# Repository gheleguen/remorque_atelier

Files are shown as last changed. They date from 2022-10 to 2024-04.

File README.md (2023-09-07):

# Une Remorque atelier

### Un support à l'animation d'ateliers de coopérations

---

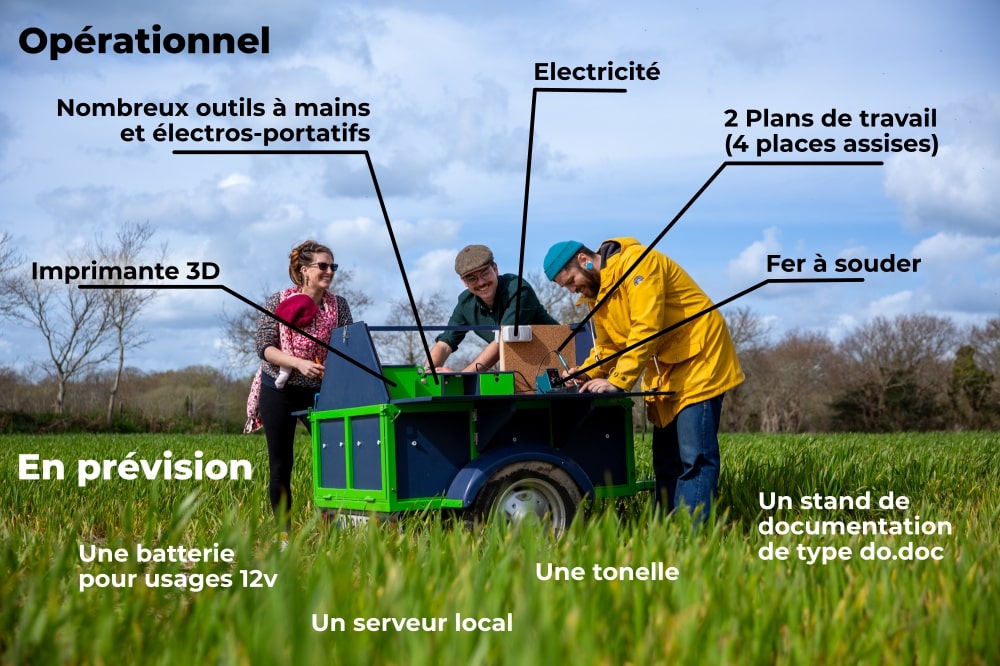
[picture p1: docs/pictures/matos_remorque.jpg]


Faciliter des ateliers coopératifs en tous lieux, étendre les buts des Fab Lab et autres ateliers coopératifs, pouvoir se déployer hors les mures, pour toucher d'autres publics, animer des lieux de passages. Tel est l'objectif de cette petite remorque.

Ma conception est voulu comme open source, je documente mes travaux, mes idées, mes conceptions. Que vous souhaitiez reproduire cet outil à l'identique ou simplement vous en inspirer, vous trouverez ici je l'éspère un maximum d'informations pour vous lancer. 
 
En cas de besoin n'hésitez pas à me contacter. Vous trouverez mes coordonnées ici : https://www.guillaumeleguen.xyz/contact.html. 

## 1/ Toutes les clés pour se lancer

### 1.1 Télécharger l'archive

Avant toute chose, [télécharger l'archive du projet](https://github.com/gheleguen/remorque_atelier/archive/refs/heads/main.zip). C'est dans ce dossier que se trouve tous les fichiers de doicumantations mais aussi les fichiers de découpes ou les modèles d'impression 3D. 

**Ou passer par Git Hub**

Se rendre dans le [git hub](https://github.com/gheleguen/remorque_atelier) et télécharger l'archive complète du projet. 

**Ou en lignes de commandes**

 - Ouvrir un terminal linux,
 - Si ce n'est pas déjà fait installer ```git``` : <pre>sudo apt install git</pre>
 - Se placer dans le dossier de votre ordinateur où vous souhaitez installer enregistrer l'archive.
 - Cloner l'archive : <pre>git clone https://github.com/gheleguen/remorque_atelier</pre> 

### 1.2 L'arborescence de l'archive

 - **docs :** Est le dossier qui contient les documents et images qui constituent la documentation.  Ce sont des fichiers marckdown (.md) que l'on peut ouvrir avec un éditeur de texte.

 - **Hardware :** Le dossier qui contient les fichiers d'impressions 3D, de découpe laser...

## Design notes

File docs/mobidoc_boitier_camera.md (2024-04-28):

# Caméra pour Mobidoc
## 1/ Introduction
La caméra est l'élément central de la station de documentation mobidoc. La documentation de [l'atelier des chercheurs](https://latelier-des-chercheurs.fr/) propose d'utiliser une webcam USB. J'ai fais le choix d'utiliser plutôt une camér raspberry pour sa facilité d'usage avec une raspberry pi.

J'ai donc choisis la configuration suivante :
 * D'utiliser la pi cam HQ (Haute Qualité).
 * Avec un convertisseur CSI HDMI pour avoir un câble HDMi qui est plus facile à manipuler que la nappe. 
 * Un objectif à focale variable. 
 
<section style="border: 2px solid; padding: 20px; border-radius:20px;" >
Cette version est un dérivé du travail produit par l'atelier des chercheurs :
	<p xmlns:cc="http://creativecommons.org/ns#" xmlns:dct="http://purl.org/dc/terms/"><a property="dct:title" rel="cc:attributionURL" href="https://latelier-des-chercheurs.fr/docs/station-de-documentation">Mobidoc</a> by <a rel="cc:attributionURL dct:creator" property="cc:attributionName" href="https://latelier-des-chercheurs.fr/">L'atelier des chercheurs</a> is licensed under <a href="https://creativecommons.org/licenses/by-nc-sa/4.0/?ref=chooser-v1" target="_blank" rel="license noopener noreferrer" style="display:inline-block;">CC BY-NC-SA 4.0</a></p>
</section>

## 2/ Matériel et fournitures
### 2.1 Fournitures

|Dénomination|Visuel|Mes fournitures|Qt|
|---|---|-----|--|
|Pi camera HQ|Picam HQ|[GoTronic](https://www.gotronic.fr/art-camera-hq-12-mpx-c-cs-sc0261-33781.htm)|1|
|Convertisseur CSI HDMI pour pi cam|Convertisseur CSI HDMI|[Gotronic](https://www.gotronic.fr/art-extension-camera-csi-via-hdmi-b0091-34398.htm)|1 lot de 2|
|Câble HDMI|||1|
|Filament PETG ou PLA pour imprimante 3D|||4m|
|Vis M2*8mm|||4|
|Visserie M2,5||||
|Vis M6*30mm tête hexagonale|||1|
|Ecrou M6|||1|
|Entretoises en laiton M2,5*5+5mm|||3|
|Entretoises en laiton M2,5*11+6mm|||3|
|Rondelles M2,5|||3|

### 2.2 Matériel
 * Imprimante 3D ;
 * Clés alens ;
 * Tournevis ;

### 2.3 Impressions
 * Boitier pour caméra Pi HQ ;
 * Couvercle pour caméra Pi HQ :
 * Rotule ;
 * Rotule femelle ;
 * 2 vis ;

## 3/ Assemblage
 * Positionner l'écrou M6 dans son emplacement au fond du boîtier ;
![Positionner l'écrou M6]()
 * Insérer la vis M6*30mm dans la rotule ;
 * Visser la rotule à l'arrière du boitier ; 
![Visser la rotule]()
 * Rassembler, 4 vis M2*8mm et un convertisseur CSI HDMI ;
![Rassembler, 4 vis M2*8mm et un convertisseur CSI HDMI]()
 * Positionner le convertisseur CSI HDMI ;
 * Veiller à placer le connecteur HDMI face à l'ouverture ;
 * Visser le convertisseur au fond du boîtier à l'aide d'une clé allen ;
![Positionnement du convertisseur CSI HDMI]()
 * Rassembler 3 entretoises en laiton M2,5*5+5mm ;
![Rassembler 3 entretoises en laiton]()
 * Visser les 3 entretoises aux emplacements prévus ; 
![Visser les 3 entretoises]()
 * Connecter la nappe à la picam. Attention ! La partie bleu doit se retrouver sur le dos de la caméra.
![Connecter la nappe]()
 * Rassembler 3 entretoises M2,5*11+6mm et 3 rondelles M2,5;
![Rassembler 3 entretoises M2,5*11+6mm et 3 rondelles M2,5]()
 * Positionner la piCam sur son emplacement ;
 * La maintenir en vissant les 3 entretoises avec une rondelle pour supprimer le jeu ;
 * Visser l'objectif en enlevant la bague C-CS ; 
![Positionner la caméra]()

 * Refermer le couvercle ;
 * Il sera nécessaire pour cela de retirer temporairement les 2 vis de réglages de l'objectif. 
 * Visser le couvercle.

## Licence
<p xmlns:cc="http://creativecommons.org/ns#" xmlns:dct="http://purl.org/dc/terms/"><a property="dct:title" rel="cc:attributionURL" href="https://remorque-atelier.readthedocs.io/fr/latest/">Mobidoc</a> by <a rel="cc:attributionURL dct:creator" property="cc:attributionName" href="https://www.guillaumeleguen.xyz/">Guillaume Leguen</a> is licensed under <a href="https://creativecommons.org/licenses/by-nc-sa/4.0/?ref=chooser-v1" target="_blank" rel="license noopener noreferrer" style="display:inline-block;">CC BY-NC-SA 4.0</a></p>

Cette version est un dérivé du travail produit par l'atelier des chercheurs :
<p xmlns:cc="http://creativecommons.org/ns#" xmlns:dct="http://purl.org/dc/terms/"><a property="dct:title" rel="cc:attributionURL" href="https://latelier-des-chercheurs.fr/docs/station-de-documentation">Mobidoc</a> by <a rel="cc:attributionURL dct:creator" property="cc:attributionName" href="https://latelier-des-chercheurs.fr/">L'atelier des chercheurs</a> is licensed under <a href="https://creativecommons.org/licenses/by-nc-sa/4.0/?ref=chooser-v1" target="_blank" rel="license noopener noreferrer" style="display:inline-block;">CC BY-NC-SA 4.0</a></p>

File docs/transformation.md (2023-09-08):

# Transformation

## 1/ Mes besoins

 Mon projet de remorque est destiné à servir de support pour animer des ateliers particulièrement pour de l'électronique, des ateliers de réparations, ou de menuiserie simple. J'ai donc besoin d'électricité à poste, avec potentiellement un mini serveur local pour partager des données. 
 
Mon souhait était également de combiner un espace qui se déploie en un geste tout en restant compacte pour la route. Mon cahier des charges était donc : 

 - Un plan de travail repliable et déployable en quelques gestes ; 
 - Pouvoir accueillir jusqu'à 4 places assises ; 
 - Un moyen de distribuer l'électricité dans la remorque et pouvoir se brancher facilement ;
 - Laisser un accés facile à quelques outils et ustensiles de bases ;
 - Intégrer une solution d'alimentation (câble et peut-être un jour une batterie.)
 - Ne pas dépasser le poids maximum (PTAC 500kg).

## 2/ Mes solutions
 - Une super-structure en bois placé sur le dessus de la remorque comportant 2 plateaux pouvants se déployer.
 - Ces plateaux reposent sur des supports rétractables. 
 - On peut entre les deux côtés de la remorque poser des cloisons avec des étagères, tirroirs, trappes. 
 - Un touret de câble sera placé dans la remorque pour pouvoir alimenter les besoins de la remorque via un branchement sur secteur (Ou prise caravane). 
 
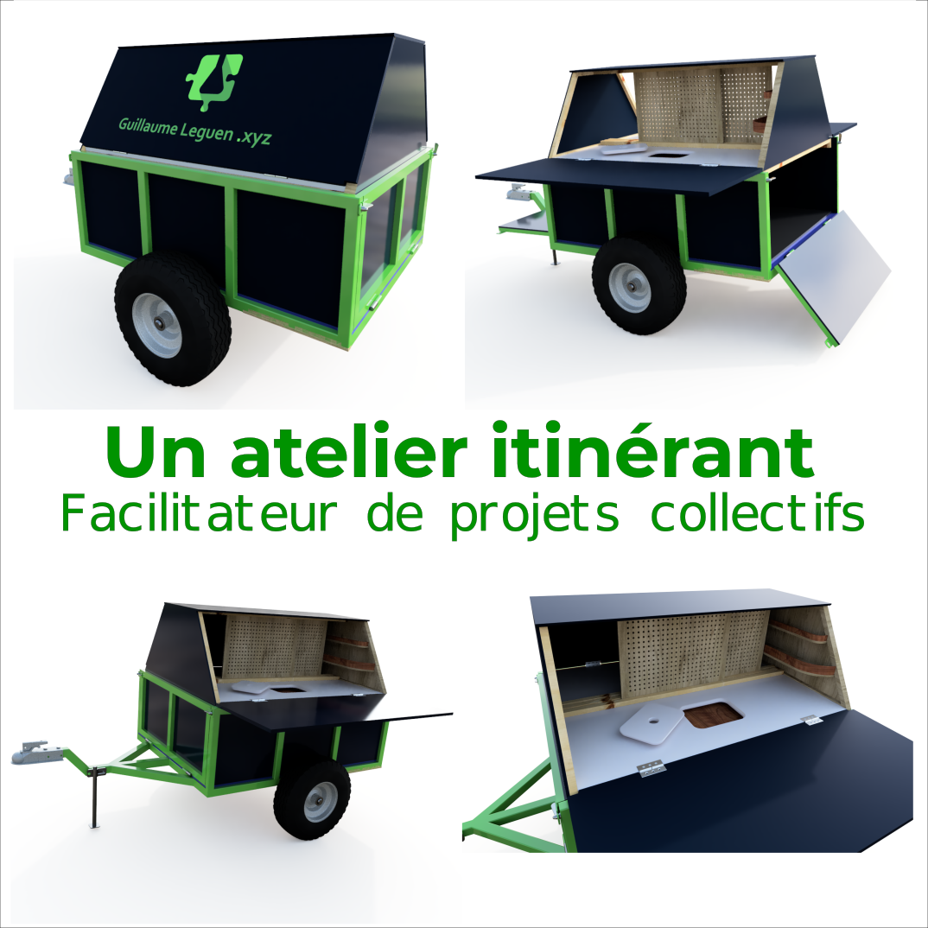
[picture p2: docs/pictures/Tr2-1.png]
projet_remorque

Notes: L'aménagement intérieur sur ce visuel n'est pas tout à fait celui que j'ai réalisé (cf. Chapitre, Amménagement).

## 3/ Réalisation 

### 1.1. La structure en bois

 - Sur les bords internes de la remorque boulonner (de préférence avec la structure) deux tasseaux à fleur du haut de la remorque. 
 - Fixer deux traverses par assemblage mi bois.
 - Attention il est nécéssaire de réaliser cela en s'assurant qu'il est bien possible de fermer les portes de la remorque. 
 - Le fait de boulonner et non visser ce cadre va permettre de pouvoir par la suite désolidariser la super-structure de la remorque et permettre ainsi de pouvoir utiliser la remorque seule occasionellement. 
 - On peut ajouter deux traverses en bois, pour soutenir le futur plateau. 

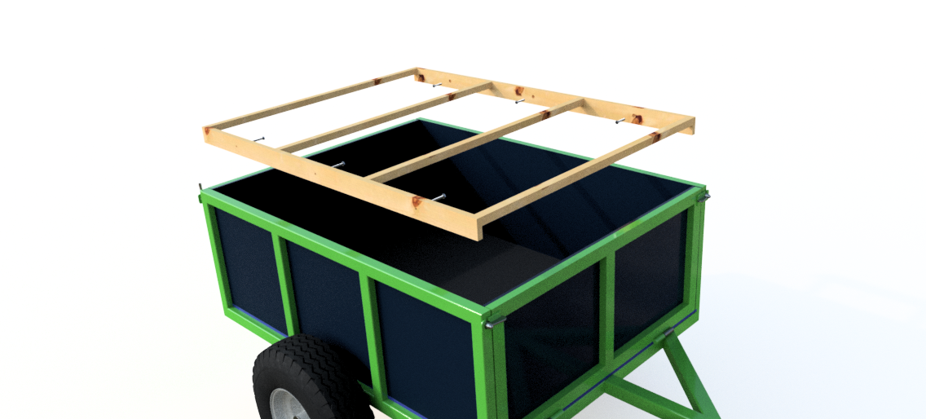
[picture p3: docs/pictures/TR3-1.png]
TR3-1

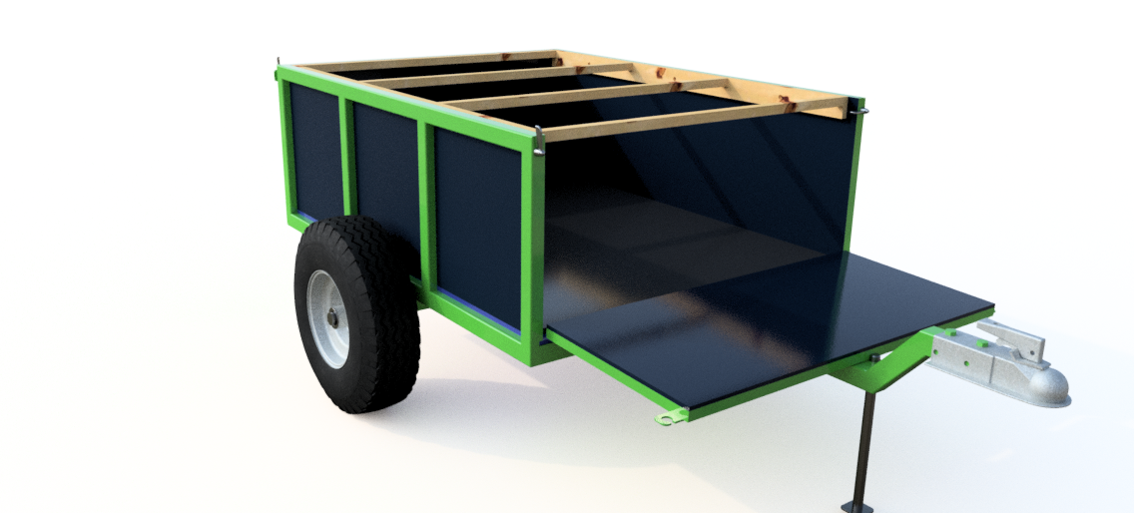
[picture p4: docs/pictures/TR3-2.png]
TR3-2


 - Fabriquer en bois 2 trapèzes à l'aide de tasseaux (dans mon cas 21*21mm en pin).
 - Visser ces trapèzes perpendiculairement à la remorque, en solidarisant le bord long vers le bas. 

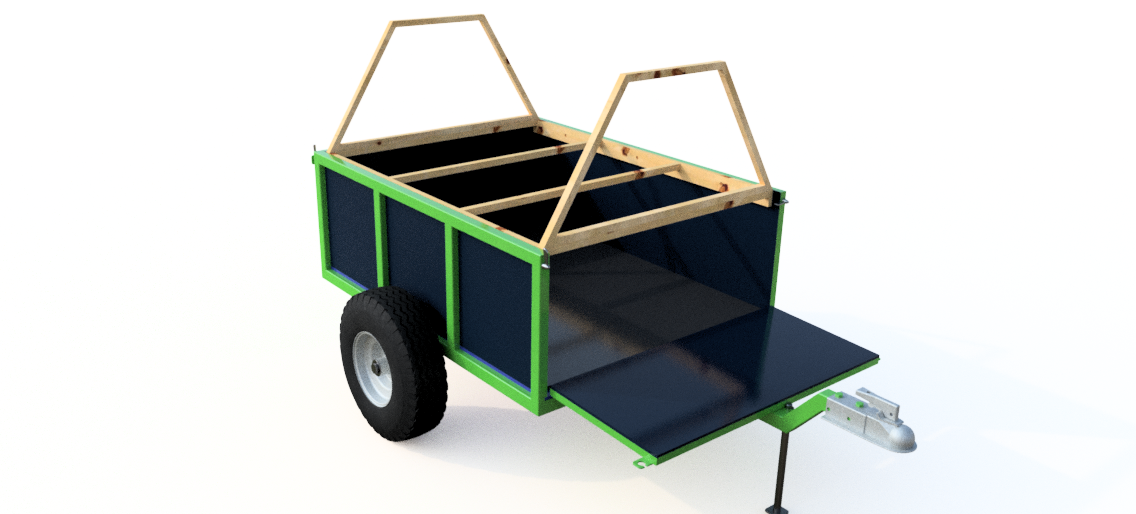
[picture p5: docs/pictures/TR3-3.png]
TR3-3


 - Mesurer la distance séparant les deux trapèzes au plus près du bord de la remorque. Si la remorque est bien parallèle la mesure prise au côté opposé devrai être rigoureusement la même. 
 - Réaliser une traverse qui sera placé au sommet de la superstructure,  elle permettra de maintenir les 2 trapèzes bien parallèle. 
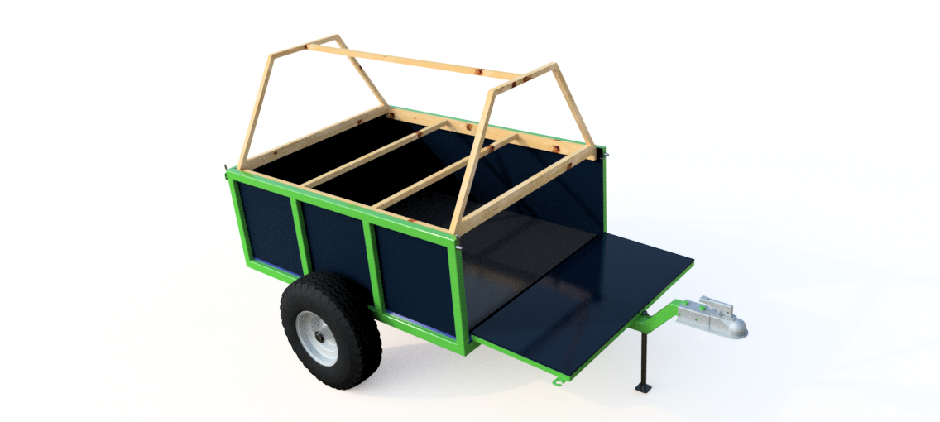
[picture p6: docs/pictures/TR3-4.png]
TR3-4


 - Le long des trapèzes visser 2 tasseaux permettant de soutenir le plateau qui viendra se poser là. 
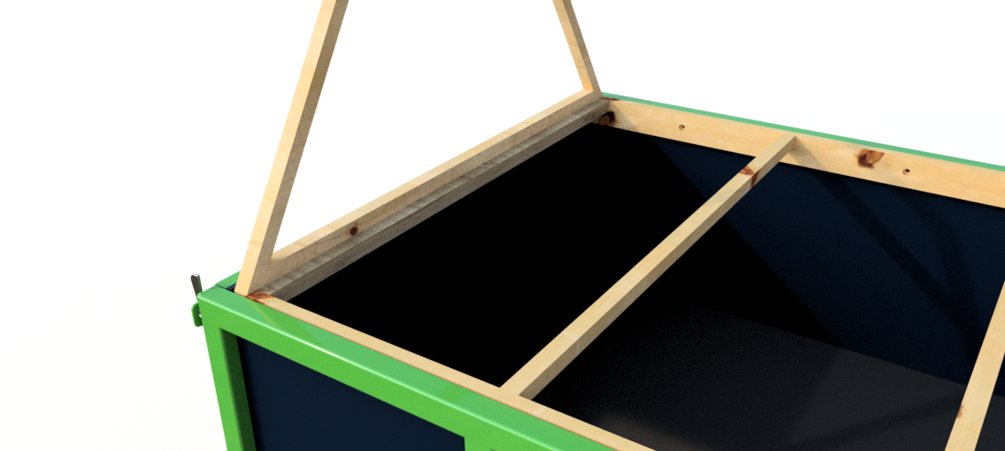
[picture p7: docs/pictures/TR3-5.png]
TR3-5


### 1.2 Découpe et poses des plateaux

 - Prendre scrupuleusement les mesures nécessaire du plateau. Largeur et longueur. Attention : Prendre une largeur à l'intersection du plateau et du trapèze. L'arrête du plateau ne devra pas dépasser des trapèzes. Cette vigilence est importante afin de s'assurer que les deux plateaux sur charnières puissent se fermer en s'appuyant sur les deux trapèzes.
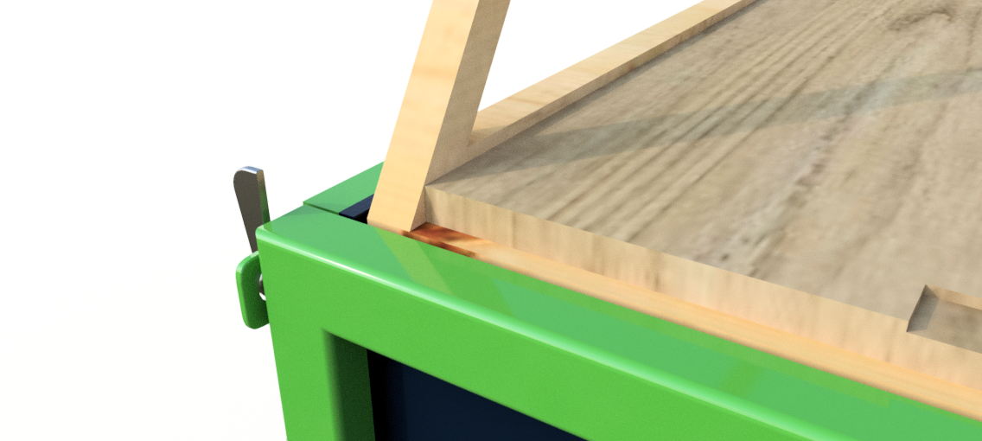
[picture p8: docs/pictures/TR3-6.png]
TR3-6


 - Découper un plateau centrale en respectant scrupuleusement les côtes défini précédamment. 
 - Positionner ce plateau. S'assurer qu'il correspond au besoin.
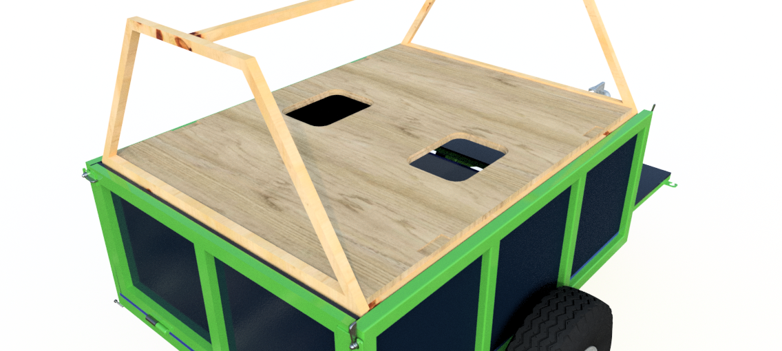
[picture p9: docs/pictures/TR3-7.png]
TR3-7


 - On pourra si on le désire effectuer dans ce plateau des trous permettant de réaliser des rangements sous la plateau par exemple. Dans mon cas, j'ai réalisé cette perforation avec un gabarit, une défonceuse et une bague à copier. Enfin, j'ai réalisé un épaulement au moyen d'une fraise à copier. 
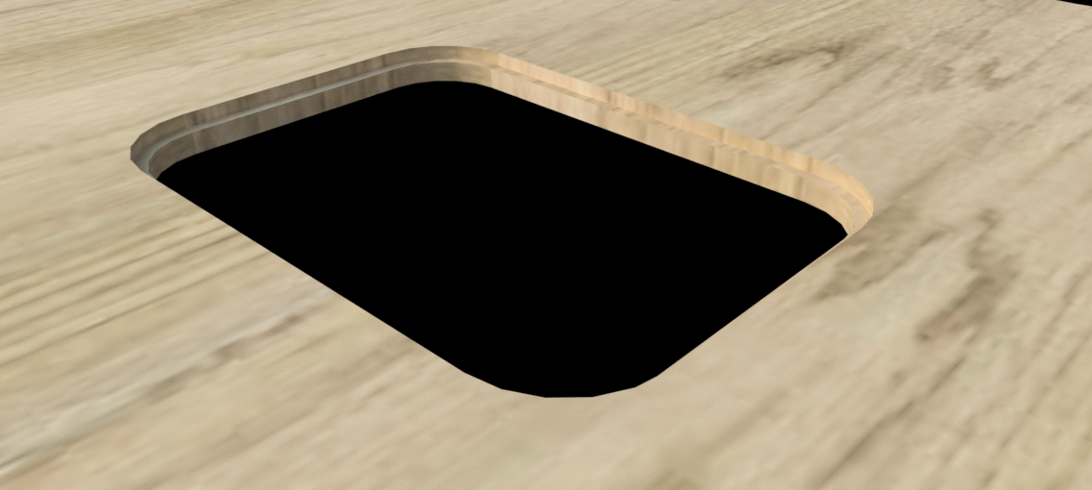
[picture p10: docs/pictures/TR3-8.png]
TR3-8


 - Découper dans du contreplaqué d'eppaisseur 10mm deux trapèzes dont la hauteur sera rigoureusement la même que ceux construit en tasseaux précademment. La largeur de ces trapèze devront être élargi de manière à dépasser de la structure en bois de chaque coté. Le dépassement sur les bords obliques devra être le même que celui de l'eppaisseur des deux plateaux mobiles. 
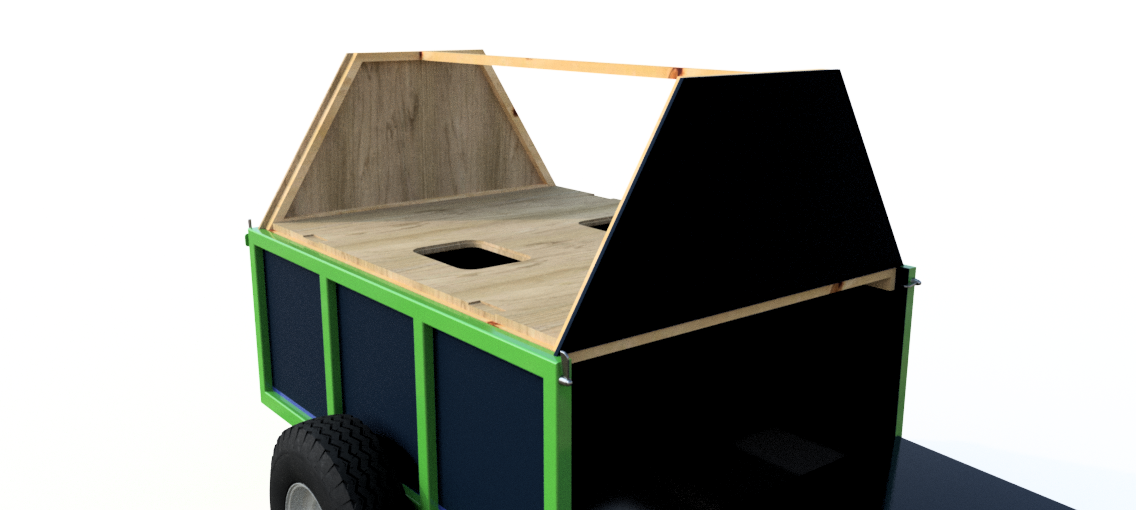
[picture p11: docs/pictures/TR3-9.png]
TR3-9

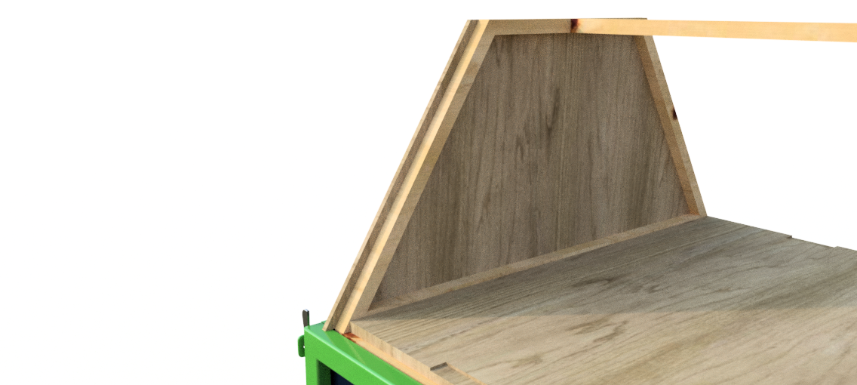
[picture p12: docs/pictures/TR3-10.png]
TR3-10


 - Découper les 2 plateaux mobiles dans du contre-plaqué de même éppaisseur que le plateau central. La longueur de ces plateaux doit permettre à ces derniers de s'appuyer sur les montants des trapèzes . Ces panneaux doivent pouvoir s'appuyer sur ces derniers. Une longueur à laquelle on retranchera une marge de l'ordre de 5 à 10mm afin de laisser un jour de par et d'autres des plateaux mobiles. Pour ce qui est de la largeurd des panneaux mobiles, s'assurer qu'ils dépassent de la structure afin de permettre plus tard une coupe oblique.

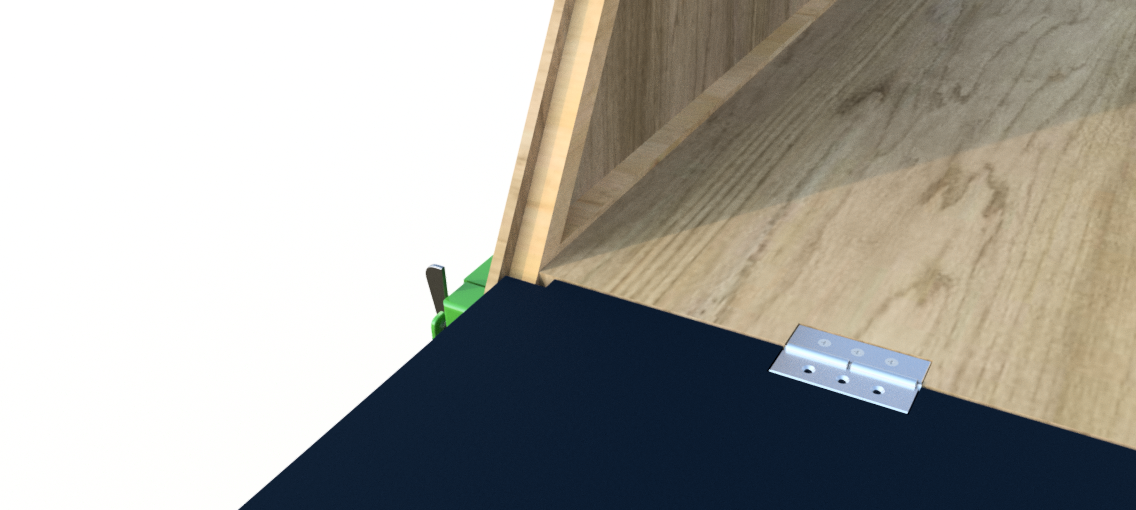
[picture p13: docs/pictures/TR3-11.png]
TR3-11

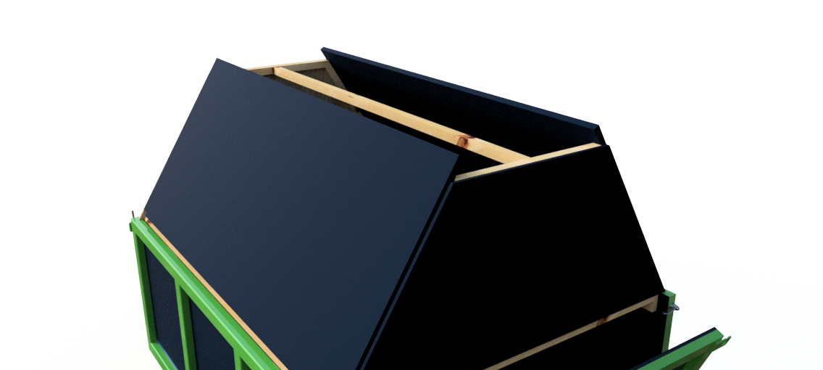
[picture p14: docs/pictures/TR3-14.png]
TR3-14


- Il est probable que l'angle des trapèzes en bois posent problème en position déplié. Pour laisser le plateau se déplier sans blocage. Il existe deux solutions. (1) Couper le morceau qui dépasse du plateau central ou (2) scier dans les plateaux mobiles une encoche, comme présenté ci-dessous. J'ai obté pour la première option. 

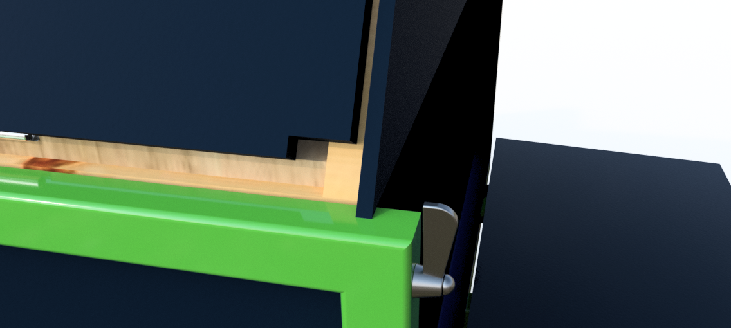
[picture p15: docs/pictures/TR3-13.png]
TR3-13


- Positionner ces plateaux le long du plateau central. Les plateaux mobiles affleurent-ils au plateau central ? Dans mon cas, le plateau central était 3 mm plus bas que les plateaux mobiles. Ceci est du au fait que les montants de ma remorque sont plus haut que la structure en bois que nous avons vissé à l'intérieur. Pour corriger cela, j'ai placé une baguette de bois de 3mm entre le plateau central et le bois sur lequel il repose. 
- Afin que les charnières ne dépassent pas, creuser au sciseau à bois des renfoncements de manière à ce que l'axe des charnières soit dans le prolongement de l'arrête haute du plateau central. 
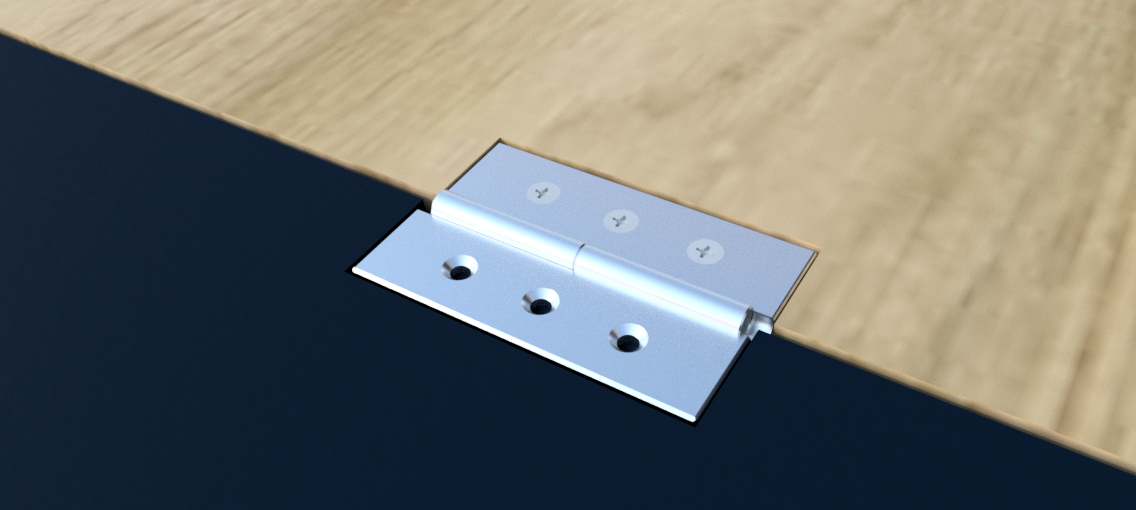
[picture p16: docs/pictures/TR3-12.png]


- Une fois replié, le plateau doit se loger entre les deux trapèzes en contreplaqué et venir s'appuyer sur les montants en bois. 
- Visser les plateaux mobiles avec les charnières en prenant garde à laisser 1mm d'espace entre les deux plateaux en position déplié.
- A l'aide d'une scie circulaire scier les plateaux mobiles au bon angle afin que les bords de splateaux mobiles ne dépassent pas du trapèze en position replié. Attention il pourra être par la suite nécéssaire d'ajouter un joint adhésif. Auquel cas prévoir l'espace nécéssaire. 

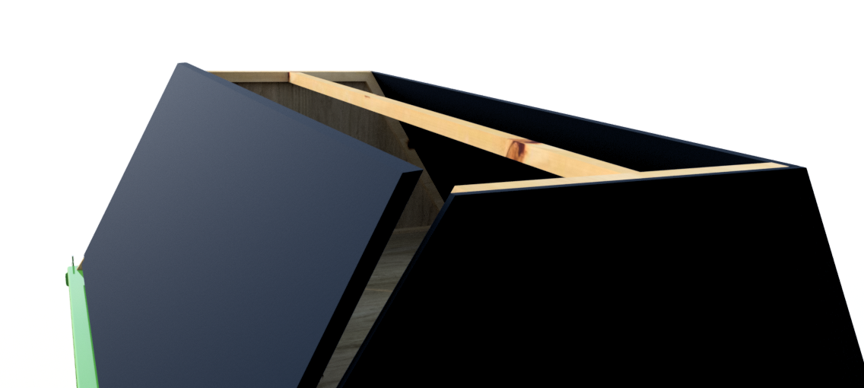
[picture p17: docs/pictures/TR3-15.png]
TR3-15


### 1.3 Renforts

 - Afin d'équérrer la structure et d'éviter à cette dernière de plier lors du transport, j'ai ajouté un panneau en bois. Celui-ci a une longueur égale au tiers de l'espqce entre les deux trapèzes. J'ai pris une attention partivulière à obtenir une planche aux angles le plus droit possible. Un tasseau permettra de visser cette planche au plateau central. 

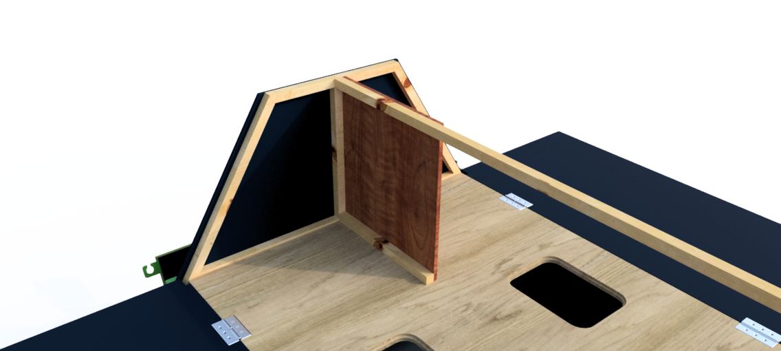
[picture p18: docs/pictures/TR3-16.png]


 - A l'opposé on peut ajouter un tasseau de bois en travers permettant de reprendre les efforts verticaux. Celui-ci sera vissé au trapèzes en contrplaqué au moyens de vis à bois. 

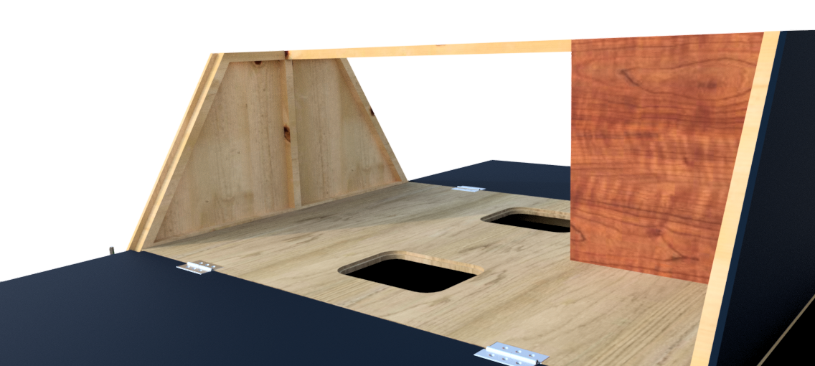
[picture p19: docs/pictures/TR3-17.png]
TR3-17


 - Afin de supporter les plateaux mobiles une fois dépliés, j'ai posé 4 equerres découpé dans une planche de contreplaqué de 15mm minimum. 
 - Ces equerres sont montés sur charnières de manière à pouvoir les (1) plier pour les transport. Dans cette position ces pièces de bois sont maintenu par des aimants puissants que j'ai incrusté dans le bois et collé à la colle PU. (2) Et déplier pour soutenir les deux plateaux mobiles en position déplier. 
 - Les charnières doivent être inscrustés dans le bois pour permettre une adhérence parfaite en position plié.
 - Les aquerres doivent être positionnés de manière à ce que les plateaux soit bien horizontaux une fois dépliés. 
 - Les charnières sont maintenues à la remorque par des vis que l'on peu visser dans les montants au moyen dans mon cas de trous taraudés, voir de rivets. 

### 1.4 Couvercle
**Détails à venir**

Le couvercle est réalisé en contreplaqué de 10mm. J'ai vissé des baguettes quarts de ronds sur les cotés pour bloquer l'ouverture des plans de travail. 

Deux fermetures à levier avec anneau à cadenas peuvent se placer sur les côtés afin de bloquer l'ouverture de la caisse

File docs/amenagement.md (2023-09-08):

# Aménagements intérieur

## 1/ Besoins et Solutions
### 1.1 Mes besoins
Afin de faciliter l'installation, j'ai fait le choix d'installer des rangements afin de garder à porté de mains des outils courants tel que un jeu de tournevis, de pinces, et quelques boites qui pourraient contenir de la visserie ou des pièces courantes. Tous ces rangements devront être bloqués pour ne pas s'ouvrir durant le voyage. A cela j'ai ajouté sur la partie qui sert de renfort à l'équerrage, 4 prises électrique 220V et un tableau en liège pour l'affichage. Une dernière contrainte se pose pour les rangements qui devront être le plus possible accessible du côté gauche comme du côté droit. 
On pourrait également prévoir :

 - Un Haut Parleur Bluetooth pour la musique
 - Un serveur locale
 - Un bloc pour ranger quelques livres.
 - Ruban LED ;  

### 1.2 Mes solutions
Je vais réaliser :

 - 3 tiroirs bloqués par des boutons de caravanes s'ouvrant dans les deux sens. Dans ces tiroirs pourront êtres rangés, tournevis, pinces et autre petit matériel de bricolage. 
 - Un bloc à portes pour des boites de visseries, et autres petites fournitures. 
 - Un panneau de liège ;
 - Deux trappes pour accéder à l'intérieur de la remorque ou créer un rangement pour les crayons, réglets et blocs notes. 

</br></br>
## 2/ Matériel et fournitures
### 2.1 Fournitures
|Dénomination|Visuel|Où se fournir ?|Qt|
|---|---|-----|--|
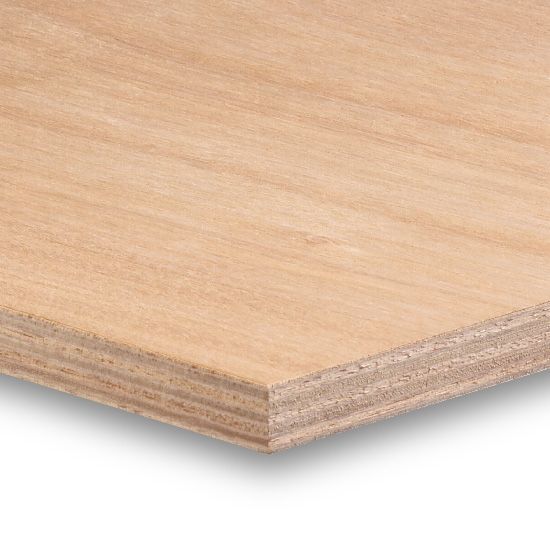
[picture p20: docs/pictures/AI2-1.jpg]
AI2-1
|Contreplaqué 10mm||Magasin de bricolage|voir fichiers svg|
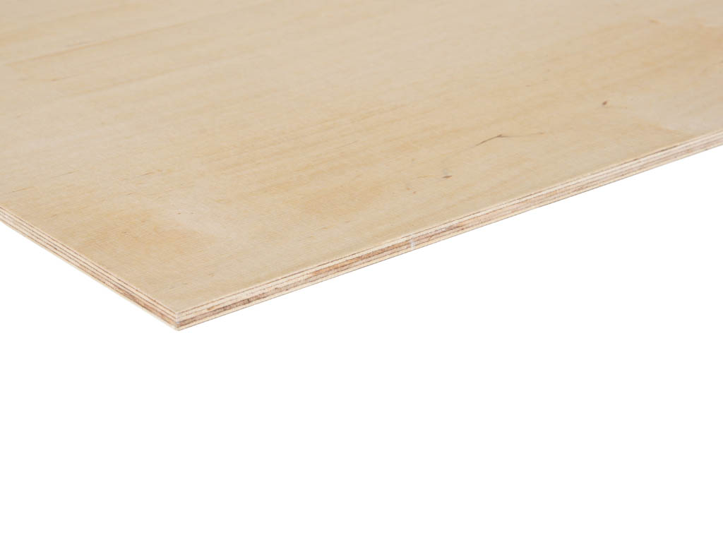
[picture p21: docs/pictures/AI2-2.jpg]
AI2-2
|Contreplaqué 5mm||Magasin de bricolage|voir fichiers svg|
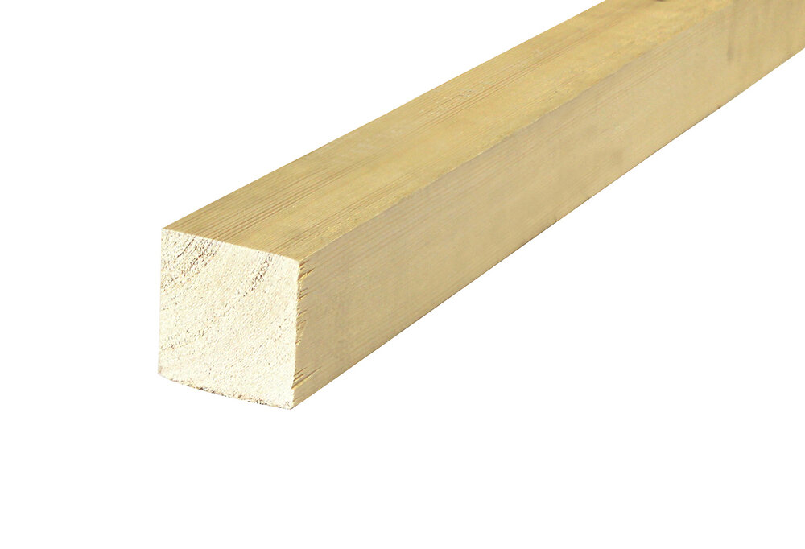
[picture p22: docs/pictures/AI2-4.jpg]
AI2-4
|Tasseau de 21*21mm||Magasin de bricolage|1|
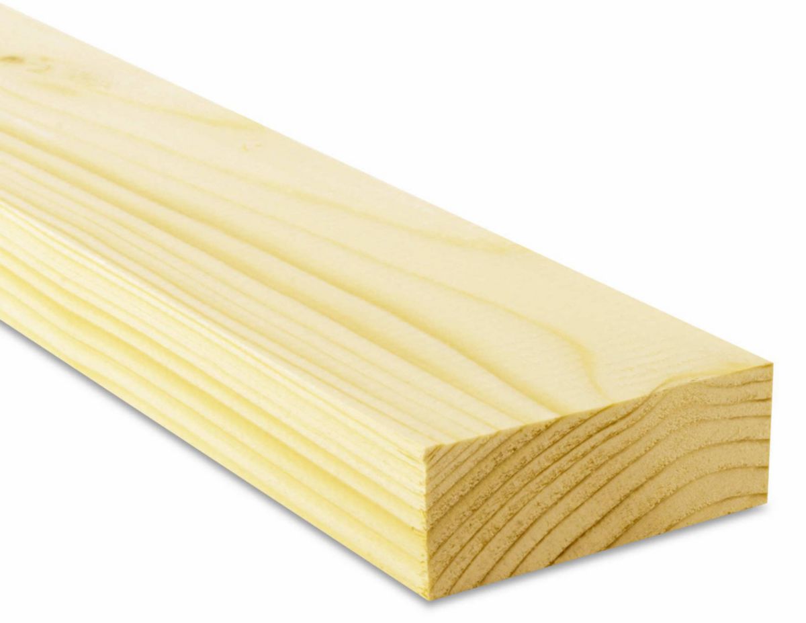
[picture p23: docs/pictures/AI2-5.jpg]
AI2-5
|Tasseaux de 9*27mm||Magasin de bricolage|2|
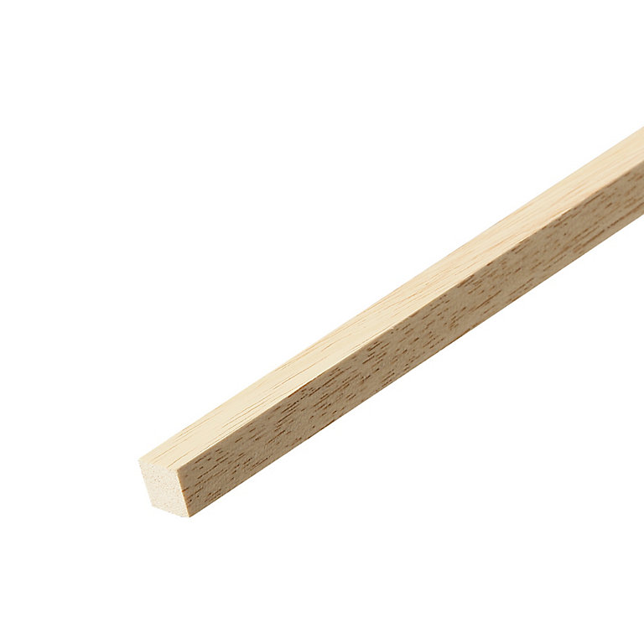
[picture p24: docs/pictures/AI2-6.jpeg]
AI2-6
|Tasseau de 13*13mm||Magasin de bricolage|1|
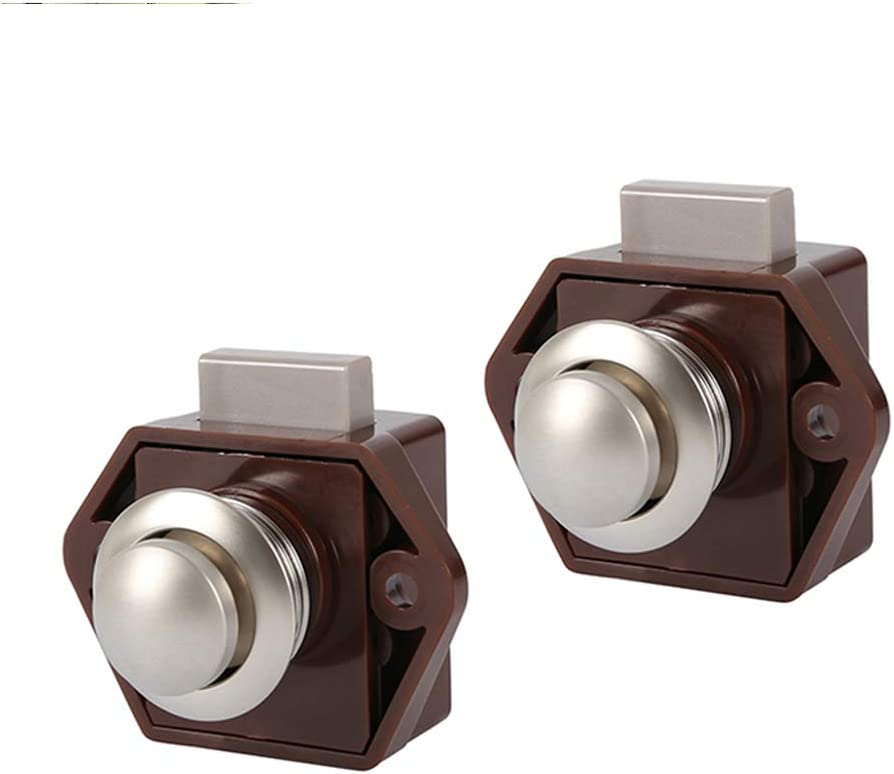
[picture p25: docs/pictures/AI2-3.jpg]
AI2-3
|Loquet, boutons poussoirs de caravane||[Amazon](https://www.amazon.fr/Poussoir-Serrure-Fermoir-Caravane-d%C3%89paisseur/dp/B08P6ZFF7T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) ou magasin de caravaning ou d'accastillage bateau|4|

### 2.2 Matériel utilisés

 - Colle à bois ;
 - Découpe Laser ou fraiseuse ou scie sauteuse, à chantourner;
 - Visserie ;
 - Équerre ;
 - Défonceuse ; 
 - Fraise cylinrique de 6mm ;
 - Imprimante 3D et filament adapté ;
 - Serre-joints ;
 - Tournevis court ;
 - Vis à bois et boulonneries ;

</br></br>
## 3/ Réalisation
### 3.1 Préparation des pièces
**3.1.1 Découpe Laser**</br>
A l'aide d'une machine à découpe laser, capable de découper du contreplaqué de 10mm, ou bien d'une fraiseuse à commande numérique, découper les pièces permettant de construire les meubles et les tiroirs. 
Les fichiers de découpes pour cette partie se trouvent dans dans le dossier "SVG_files" présent à la racine du dépôt.

|Nom du fichier|Visuel|Matériau|Qt|
|---|---|----|---|
|meubles_interieur_10mm.svg|AI2-7|Contreplaqué 10mm, planche de min 600*1000mm|1|
|tiroir_10mm.svg|AI2-8|Contreplaqué 10mm, 3 planches de min 600*270mm |3|
|tiroir_5mm.svg|AI2-9|Contreplaqué 5mm, 3 planches de min 250*200mm|3|
|portes_meuble.svg|AI2-11|Contreplaqué 5mm, planche de min 270*320mm |1|

**3.1.2 Impression 3D**</br>
Imprimer en 3D de préférence en PETG ou en ABS pour une meilleure résistance 4 exemplaires du guide de porte coulissante (guide_porte.stl). Tous les modèles 3D se trouvent dans l'archive, dans le dossier "3D_models".

</br>
### 3.2 Assemblage des meubles
**3.2.1 Meuble à trois tiroirs**

 - Avec de la colle à bois, commencer à assembler le meuble à tiroirs. Encoller et placer les 4 cloisons "A" sur "D" aux emplacement définis. Attention à bien surveiller le bon équérrage des cloisons. On se servira d'équerres pour maintenir les pièces pendant le séchage. AI3-1
 - Le dessous du meuble, là où glisseront les tiroirs sera constitué de 4 tasseaux de bois de 27*9mm. Couper 4 longueur de tasseaux de 551mm chacun.   
 - Les visser sur les 4 "A" comme présenté ci dessous. Les visser permettra de les démonter pour pouvoir percer et loger la tête des vis qui permettront de fixer le meuble au plan de travail. AI3-1

**3.2.2 Meuble à portes coulissantes**

 - Commencer par réaliser une nervure au moyen d'une défonceuse de 6mm de largeur à 5 ou 6mm du bord de chaque petit coté de la pièce "B" et de 5mm de profondeur. AI3-3
  - Assembler ce meuble en collant à 90° les deux parties "B" et "C" que l'on pourra équerrer au moyen d'une baguette de 13mm de coté. AI3-4
  - Visser au raz de la fente de coulissement 2 tasseaux de 21*21 d'une longueur permettant au meuble une fois en place d'être bien équerré au plateau de la remorque. AI3-5

### 3.3 Assemblage des tiroirs
Les étapes suivantes sont à reproduire trois fois pour réaliser 3 tiroirs :

 - Coller le fond de tiroir "G" aux deux côté "F". AI3-6
 - Coller les deux avant et arrières de tiroirs "H" aux plaques "G" et "F".
 - Maintenir le temps du séchage au moyen de serre-joints. AI3-7
 - Coller les deux pièces "E" Par dessus les plaques "H" en veillant à les aligner rigoureusement. Serrer le temps de séchage. AI3-8
 - Au moyen d'un tournevis et de vis de 15mm maximum visser 2 loquets à poussoir sur chaque tiroir. Il est recommandé d'utiliser un tournevis court. Veiller à bien aligner les loquets pour que ces derniers puissent s'ouvrir et se fermer sans accrocs. 
 - Positionne rune première fois les tiroirs sur le meubles et positionner méticuleusement les butée en métals qui sont fournis avec. Cette étape est délicate, les tiroirs doivent pouvoir s'ouvrir et se fermer dans les deux sens. Pour y parvenir, la butée en métal doit pouvoir passer dans l'encoche au dessu du trou circulaire des pièces "E" et "H".

### 3.4 Installation sur la remorque
 - Installer le meuble à porte coulissante le long de la paroie et le meuble à tiroir entre ce dernier et la cloison d'équerrage. 
 - Dans mon cas j'ai vissé le meuble à porte coulissante à la parois au moyen de vis à bois et boulonné le meuble à tiroirs au plateau, en incrustant dans les tasseaux les têtes de vis (pour ne pas géner l'ouverture des tiroirs). AI3-9
 - Insérer les tiroir et les portes coulissantes. Ces dernières nécessitent e visser les 4 guides imprimés en 3D sur le meuble à porte coulissantes. AI3-10

### 3.5 Cloison
Pour ce qui est de la cloison, j'ai doublé cette dernière au moyen de tasseaux de 21mm et de contreplaqué de 10mm. L'espace entre ces deux cloisons me permettent de passer des câbles et d'alimenter 2 prises 220V étanche. J'ai recouvert une face de liège épais pour l'affichage.

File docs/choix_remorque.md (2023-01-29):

# Choix de la remorque

## 1/ Mon choix 
 
 - Petite remorque dont les dimensions sont de l'ordre du mètre ;
 - Parois en bois peint facilement démontable ;
 - Structure acier peint ;
 - Remorque artisanale restauré avec des roues de Fiat 500 ;
 - Deux portes ouvrantes ; 
 - Capacité de charge maximum (PTAC) 500kg pour 100kg à vide

visuel_remorque

## 2/ Recommandations à surveiller lors de l'achat

 - La charge maximale est à surveiller. Une première remorque visité n'avait pour PTAC que 300kg. Avec 75kg à vide, cette dernière ne pouvait être chargé que de 225kg au total. Ce qui est un peu juste pour un tel volume. 
 - Surveiller les amortisseurs ; 
 - Essayer d'ouvrir les portes ; 
 - Chercher les points de rouilles eventuels ;
 - Tester le mécanisme d'accrochage ; 
 - Tester les feux ;

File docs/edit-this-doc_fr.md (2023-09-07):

# Éditer cette documentation

## 1/ Introduction
|||
|-|-|
|Cette documentation est mise en page par ReadTheDocs.org et [lisible à l'adresse ci attaché](https://remorque-atelier.readthedocs.io/fr/latest/). En aucun cas, cette adresse permet d'éditer la documentation.|ED1-1|
|Afin de pouvoir contribuer à cette documentation, vous pouvez contribuer directement au [repository GitHub](https://github.com/gheleguen/remorque_atelier).|ED1-2|

C'est sur GitHub que sont déposés les fichiers sources. On y retrouve l'arborescence suivante : 

 - **docs :** Est le dossier qui contient les documents qui pourront être affichés sur le read the doc. Dans ce dossier sont entreposés :

   - A la racine les fichiers marckdown qui sont les textes de la documentation. Pour chaque onglet sur read the doc nous ajouterons un fichier séparé avec un titre en Anglais sans espaces terminé par "_fr" pour la version française ou "_en" pour le version anglaise. L'extention sera toujours ".md".
   - Le dossier "pictures" : Qui contient plusieurs dossiers dont chacun porte un nom en rapport avec le fichier marckdown auquel il se rapporte. Ainsi pour un fichier de doccumentation "test1_fr.md" on prendra le soin d'entreposer les images dans un dossier "/docs/pictures/test1".

 - **Hardware :** Qui est le dossier qui contient les fichiers d'impressions 3D, de découpe laser...  

Avant de faire une proposition de contribution, il est bienvenue d'éditer le repository depuis votre compte en effectuant un forke de la présente documentation. Une fois que vous aurez une version prête à être publiée il suffira de faire une pull request au "main project".
C'est un administrateur qui étudiera votre proposition pour en intégrer tout ou partie sur le projet. 

## 2/ Édition (généralités)
Ces actions peuvent se réaliser directement sur la plateforme gilhub.

### 2.1 Écriture en Marckdown
Le Marckdown est un langage de mise en forme de texte très simplifié. On peut éditer un fichier ".md" directement via gitHub ou en local de son ordinateur avec n'importe quel éditeur de texte. Cependant nous recommandons [Ghostwriter](https://ghostwriter.kde.org/fr/) qui présente l'avantage de proposer une vue en direct du rendu (aperçu HTML).

[Pour ce qui est de la syntaxe, consulter ce guide](https://www.markdownguide.org/basic-syntax/)

### 2.2 Ajout et mise à jour d'une image

#### 2.2.1 Ajout
Les images que l'on souhaite faire apparaître dans la documentation ne doivent pas être collées dans le document. 

 - Importer les images désirées que l'on aura préalablement réduites en taille chacune en dessous de 200Ko et renommées de manière à être facilement identifiables. 
 - Dans le fichier de documentation corespondant à la ligne où l'on souhaite faire apparaître l'image, ajouter la ligne suivante : 
 ```Legende_Image``` 

#### 2.2.2 Mise à jour 
Pour mettre à jour une image, il suffit de supprimer du git l'image en question et d'uploader la nouvelle image en prenant soin de renommer cette nouvelle image avec le nom exact de l'ancienne. 

## 3/ Édition du dépôt en locale (Intermédiaire)
Cette méthode permet de cloner l'archive disponible sur github sur un disque dure. Ainsi on pourra facilement modifier les différents fichiers mais aussi l'arborescence sans nécéssiter de connexion internet mais surtout cela va permettre de préparer une version qui pourra par la suite faire l'objet d'un pull request. 
Toute la démarche décrite ci-dessous est valable uniquement pour un usage depuis un ordinateur sous Linux. Il existe nécessairement des équivalent pour les autres OS mais les lignes de commandes restent les même.

### 2.1 Installer Git et préparer le terrain
 - Sur votre disque dure, définir l'espace où sera stocké le dépôt. Sachez qu'un dépôt GitHub peut peser jusq'à 500Mo. De préférence définir un dossier vide. **Attention* A ce qu'aucun dossier ou sous-dossier du chemin ne comporte de caractères spéciaux ou d'espaces. Remplacer tous les espaces par des underscore "_". 
 - Ouvrir un terminal (*Ctrl + Alt + t* sur Unbuntu).
 - Dans le cas où le paquet "git" n'est pas déjà installé sur votre PC, lancez l'installation de git :  ```sudo apt install git``` (Cette action nécessite une connexion internet).

### 2.2 Cloner le dépôt sur son disque dure
 - Ouvrir une page web avec le github que l'on souhaite cloner
 - Y copier le code "https" que l'on trouvera dans l'onglet déroulant "code" en haut à droite.
 - Dans un terminal se diriger vers l'espace prévu pour coller le dépôt. Utiliser la commande ```cd puis_chemin/de_votre_dossier```
 - Cloner le dépôt git en utilisant la commande ```git clone https://github.com/identifiant/nom_du_projet.git``` Prendre soin de remplacer l'url par celui du dépôt désiré si il est différent du notre. 
 - Le clonage va prendre quelques minutes et va coller tous les fichiers et l'arborescence dans votre répertoire.

### 2.3 Modifier le dépôt
 - Sur votre poste de travail, modifiez tous les fichiers nécessaires, déposer des fichiers, suprimez en...
 - Avant de commencer à travailler peut-être que le dépôt en ligne a été modifié depuis votre dernière mise à jour. Pour mettre à jour votre dépôt en local. Se positionner tout d'abord dans le dépôt ```cd NomduDepot``` Puis effectuer un "Pull" ```git pull```
 
### 2.4 Proposer des modifications
Si vous avez effectué des modifications, il peut-être utile de les proposer en modification au projet. Mais avant cela il peut-être utile de créer une nouvelle branche ou de faire cela depuis votre fork. 
 - Pour ajouter l'ensemble des fichiers à la liste des fichiers à commiter : ```git add *```
 - Commiter ```git commit -m "commentaire associé au commit" git@git.cru.fr:nom_projet.git nom_branche (par défaut master représentant la branche principale)```
 - Enfin pousser votre travail ```git push```

## Liens connexes
 - [Documentation Git](https://git-scm.com/about)
 - [Formation vidéo à Git](https://youtube.com/playlist?list=PLjwdMgw5TTLXuY5i7RW0QqGdW0NZntqiP)

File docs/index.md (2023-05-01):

# Introduction à la documentation
Se rendre dans le git Lab et télécharger l'archive complète du projet. De cette manière vous aurez tout le nécessaire pour suivre la documentation. 
Ou se rendre à l'adresse suivante pour consulter fichier par fichier. ^

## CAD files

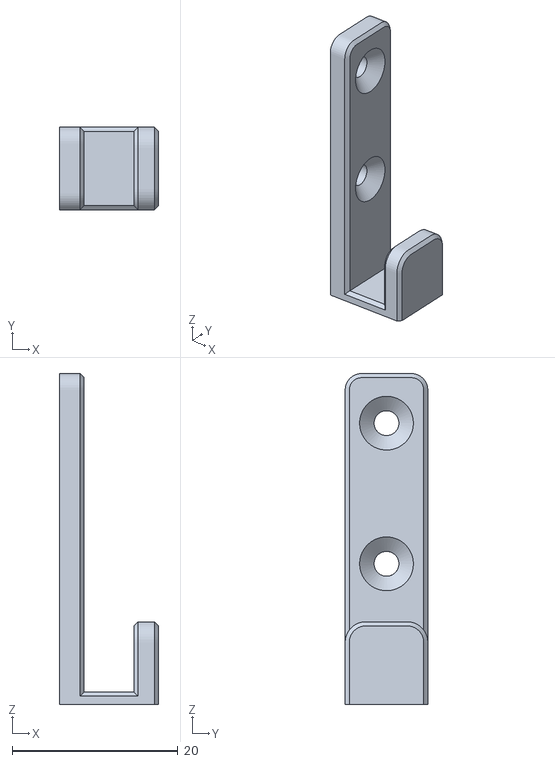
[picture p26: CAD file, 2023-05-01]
3D_models/guide_porte.stl
12.0 x 10.0 x 40.0

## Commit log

2023-02-07 ajout de trucs
2023-05-01 Fin aménagement
    [guide_porte.stl]
